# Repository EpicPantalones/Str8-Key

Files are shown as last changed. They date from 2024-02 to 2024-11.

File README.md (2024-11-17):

# The Str8-Key Keyboard

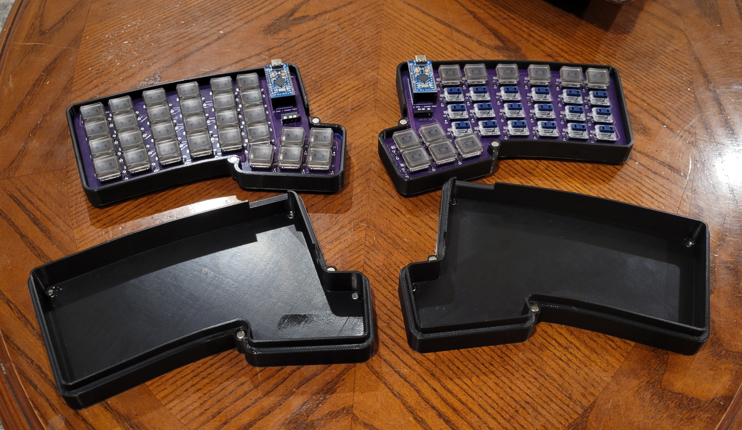
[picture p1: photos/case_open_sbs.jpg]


## Introduction

Welcome to Str8-Key, a custom mechanical keyboard in both form and function. Co-designed by Ethan Sorensen and John Rowberry, this ortho-linear, staggered, split keyboard is powered by dual Arduino Pro-Micro microcontrollers and connected via USB-C. Str8-Key bridges a fun engineering project with the great configurability of the QMK firmware, the result of which offers a unique and ergonomically safe typing experience! With 58 keys and infinite possibilities, this keyboard can be used to create layouts tailored perfectly to your workflow (or gameflow!). Built entirely from scratch, it remains an affordable project at just around $140, excluding 3D printing costs — actually a pretty good price for a fully customized typing experience.

Wow this is the 225 recitation! there are so many cool people here today.

## What You'll find in this Github:

You can look in the Tree.txt file to see a full list of all the files contained in the tree. Most of them are specific to our design, but you might find some jumping off points if you're interested in making your own.

## YAML Design

```YAML
metadata:
  engine: 4.0
  version: 1.2
  author: John Rowberry
  contact: johnrowberries@gmail.com
units:
  default_spread: 'cx'
  default_splay: 0
  default_width: 'cy'
  default_padding: 'cx'
  default_autobind: 10
  xspace: cx
  yspace: cy
  paddingy: yspace
...
and more
```

YAML (YAML Ain't Markup Language) is a human-readable data serialization format often used for configuration files. It focuses on simplicity and uses indentation to represent structure, making it easy to read and write. YAML supports key-value pairs, lists, and nested structures, and it's useful to us because Ergogen uses YAML structures to generate layouts for custom keyboards. Look at Flatfox's guide (linked below) for more info on the structure of the YAML code, but its really simple and in most cases you can reference an example like our code and get the right result.

## Board Layout

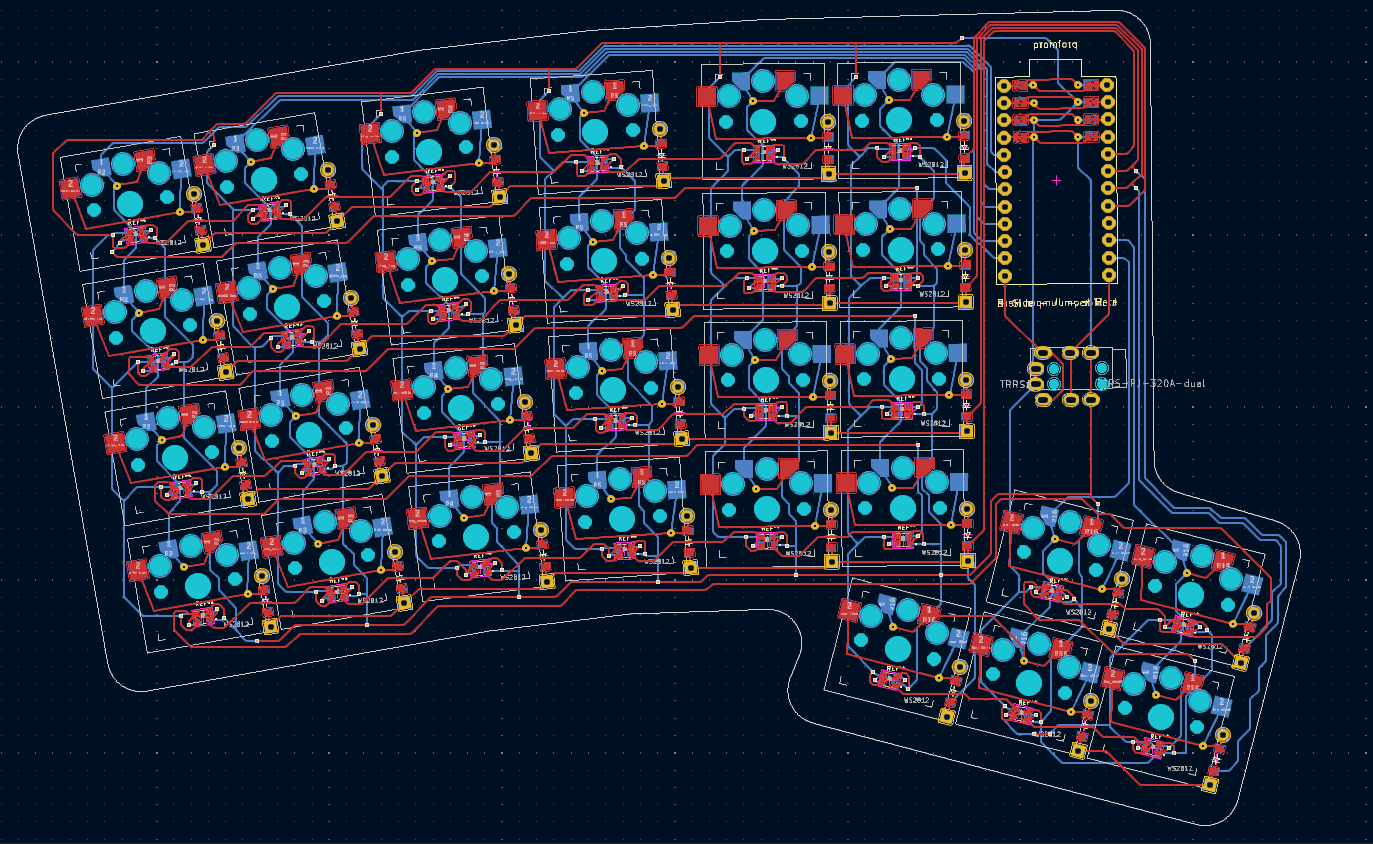
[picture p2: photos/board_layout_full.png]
the board layout

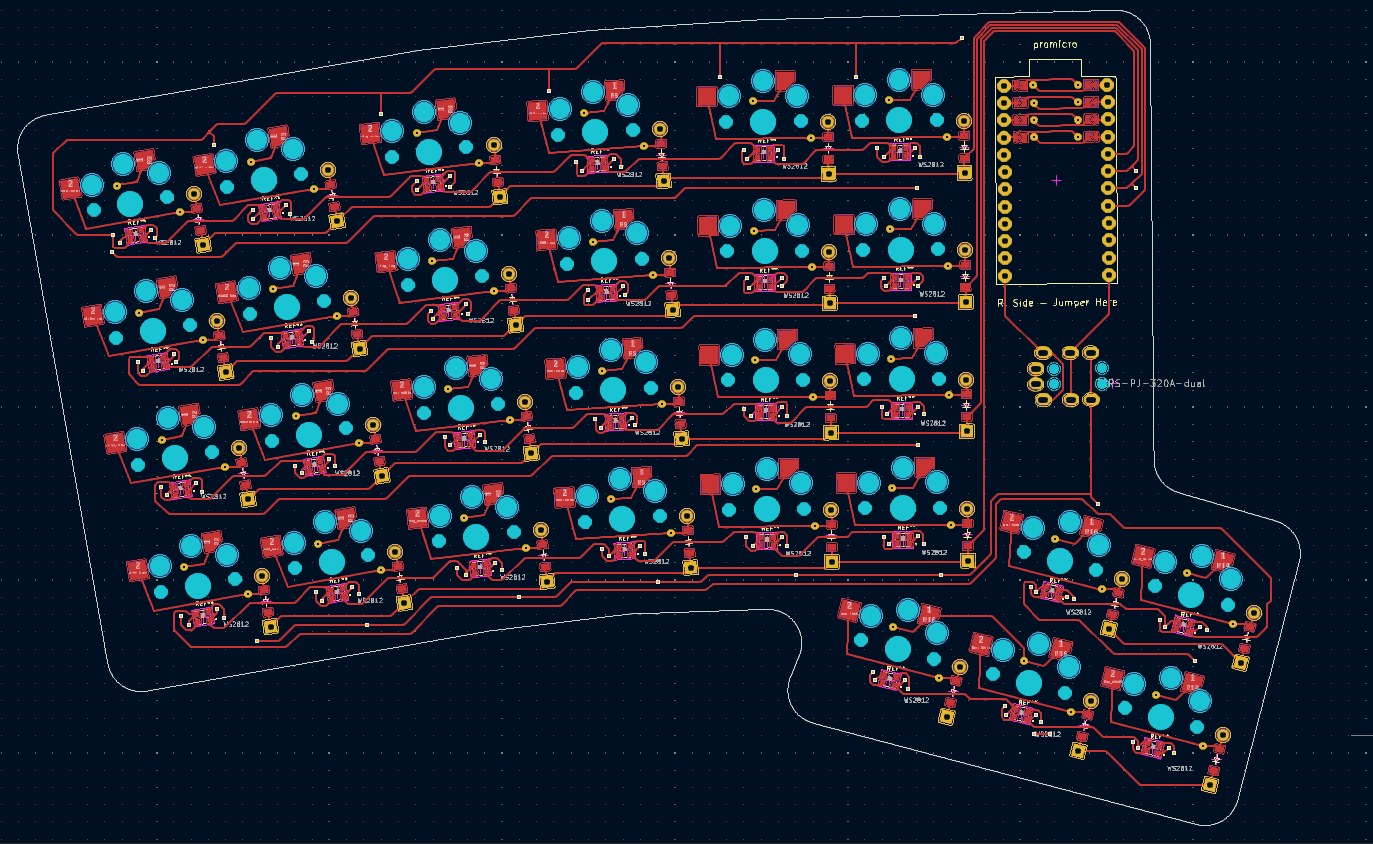
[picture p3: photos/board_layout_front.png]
the left board layout

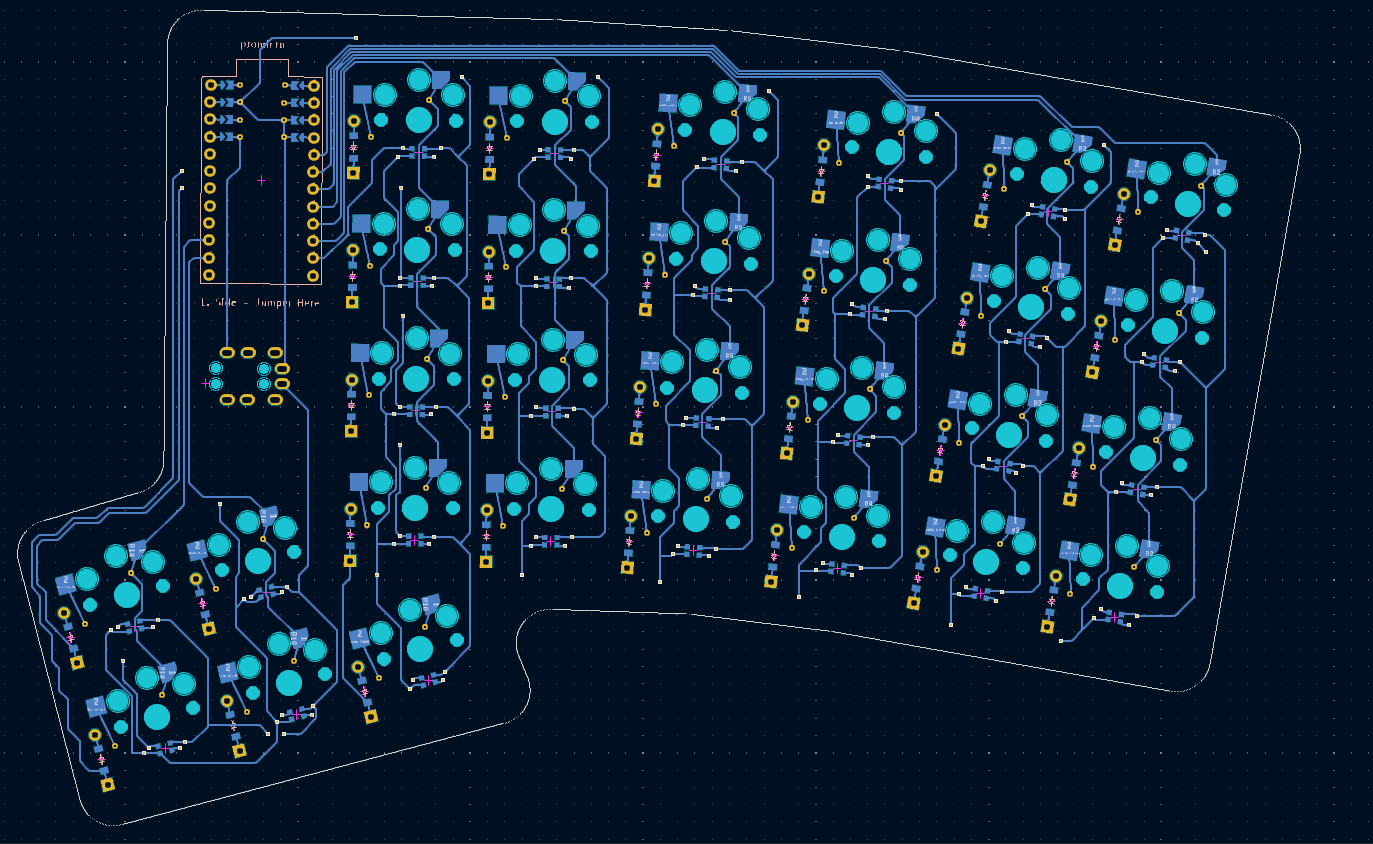
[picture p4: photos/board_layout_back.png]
the right board layout


## Final Product

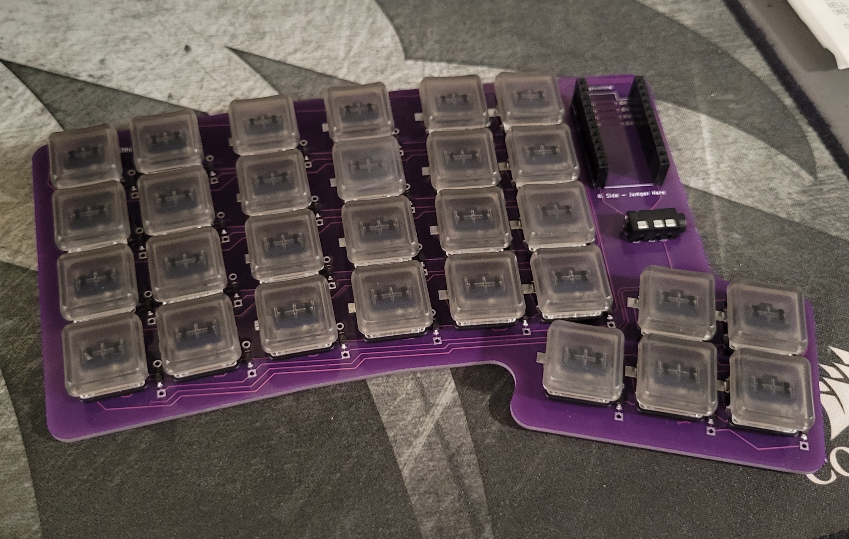
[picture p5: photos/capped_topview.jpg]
full keyboard top view

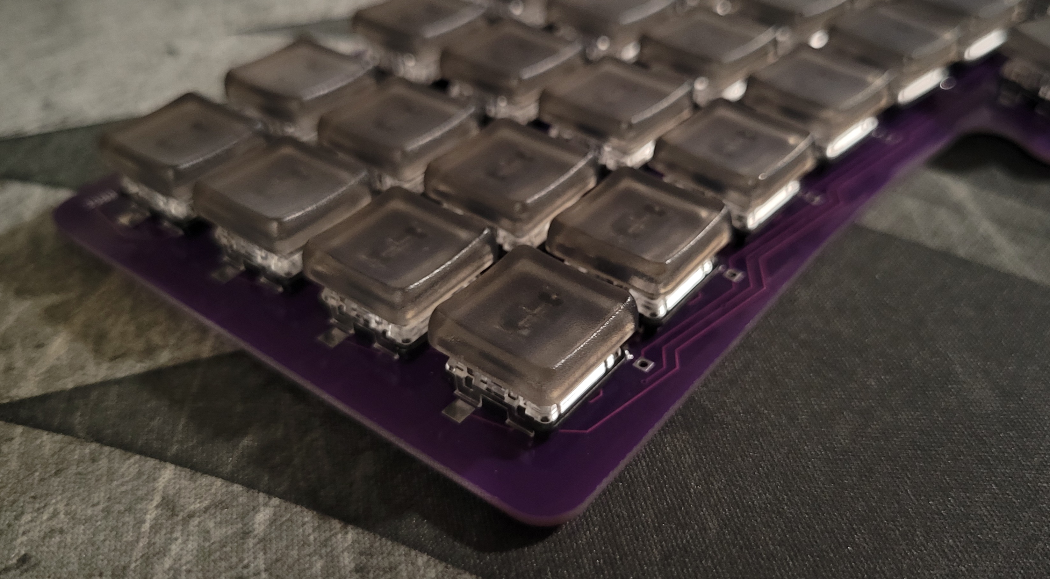
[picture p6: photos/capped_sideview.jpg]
keyboard side profile

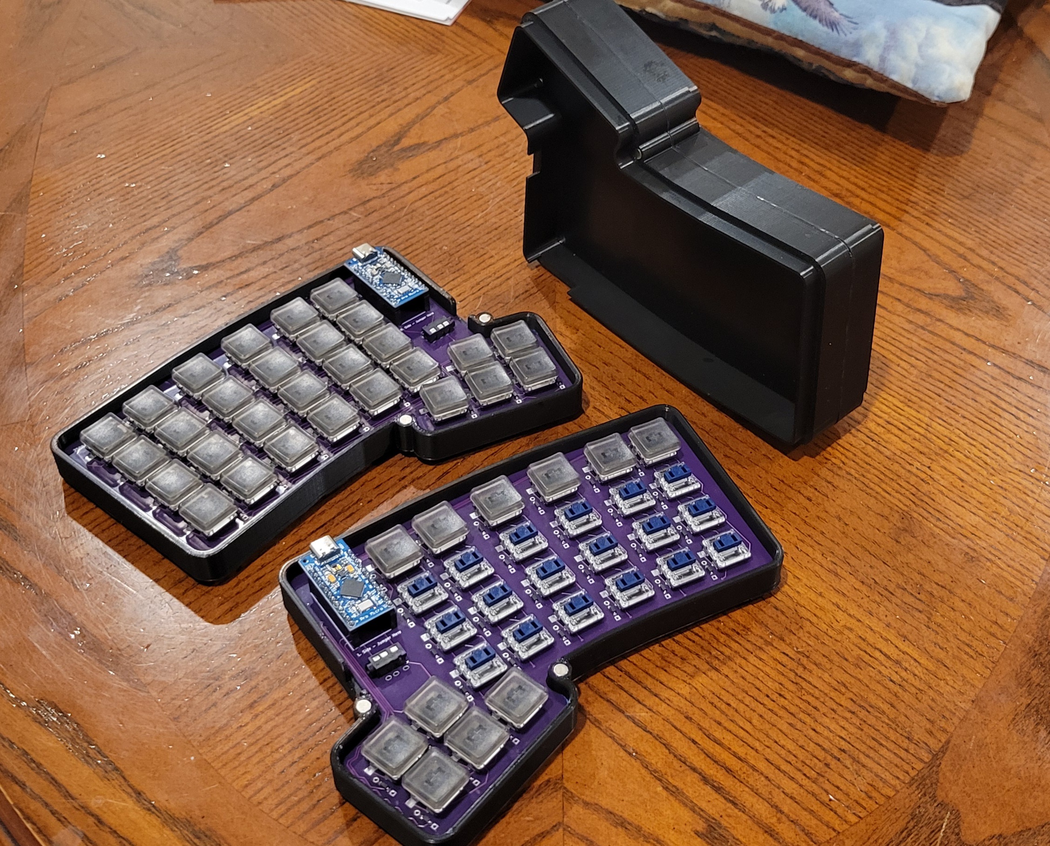
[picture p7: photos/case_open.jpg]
keyboard in opened case


## Resources we can provide for your own design:

The [**Ergogen guide by FlatFootFox**](https://flatfootfox.com/ergogen-introduction/) was instrumental in helping us bring Str8-Key to life, serving as both a comprehensive resource and our virtual teacher, alongside guidance from **BYU's IEEE Club**. Initially, we used the [**Ergogen Unofficial Website**](https://ergogen.cache.works/), which offers better real-time rendering in some cases compared to the [official site](https://ergogen.xyz/), but we eventually transitioned to running **Ergogen locally on Node**, as suggested in FlatFootFox's guide, for even greater control. [**QMK Firmware**](https://qmk.fm/) was chosen to program the keyboard, and though this is still a work in progress, it offers immense flexibility. Additionally, [**Carter's GitHub**](https://github.com/Virginia2244/BYU-IEEE-Keyboard-Project) project was invaluable, providing a template for the YAML files and saving us on more than one occasion during the build process.

## Resources for the footprint creation and KiCad stuff:

The documentation for the LEDs we chose came from the same **[Adafruit link where we purchased them](https://www.adafruit.com/product/4684)**, and I used this **[SNAP EDA footprint](https://www.snapeda.com/parts/WS2812-2020/Worldsemi/view-part/?company=BYU&)** as a starting point for the Ergogen code found in `footprints/epicpantalones/WS2812`. To ensure the choc switches fit and aligned properly, I referenced this **[choc switch datasheet](https://cdn-shop.adafruit.com/product-files/5113/CHOC+keyswitch_Kailh-CPG135001D01_C400229.pdf)**. The Ergogen code I wrote was primarily based on a guide to **[converting KiCad footprints to Ergogen](https://nilnil.notion.site/Convert-Kicad-Footprints-to-Ergogen-8340ce87ad554c69af4e3f92bc9a0898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)**, with some additional reference from this **[LED code](https://github.com/infused-kim/kb_ergogen_fp/blob/main/smd_0805.js)** that I used as a basis.

## The actual parts that we purchased:

We ordered the PCB from **[JLCPCB](https://jlcpcb.com/)**, and the price was incredibly affordable at just $13 plus shipping, totaling about $30 for five boards. The keys cost around $50, depending on the type, and we opted for **[frosted black choc switch keycaps](https://a.co/d/dT4MgD5)**, as the frosted look let the RGB lighting through. The LEDs were sourced from **[Adafruit](https://www.adafruit.com/product/4684)**. Our controller head unit is the **[Arduino Pro Micro](https://www.sparkfun.com/products/12640)**, a board we discovered during this project, and they are connected via an audio connector (links forthcoming). We also included hot-swap sockets for the choc switches, which makes customization easy, and control flow diodes, although we don't have the sourcing details or costs for those at the moment.

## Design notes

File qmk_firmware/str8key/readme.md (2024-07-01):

# str8key

str8key

*A short description of the keyboard/project*

* Keyboard Maintainer: [EpicPantalones](https://github.com/EpicPantalones)
* Hardware Supported: *The PCBs, controllers supported*
* Hardware Availability: *Links to where you can find this hardware*

Make example for this keyboard (after setting up your build environment):

    make str8key:default

Flashing example for this keyboard:

    make str8key:default:flash

See the [build environment setup](https://docs.qmk.fm/#/getting_started_build_tools) and the [make instructions](https://docs.qmk.fm/#/getting_started_make_guide) for more information. Brand new to QMK? Start with our [Complete Newbs Guide](https://docs.qmk.fm/#/newbs).

## Bootloader

Enter the bootloader in 3 ways:

* **Bootmagic reset**: Hold down the key at (0,0) in the matrix (usually the top left key or Escape) and plug in the keyboard
* **Physical reset button**: Briefly press the button on the back of the PCB - some may have pads you must short instead
* **Keycode in layout**: Press the key mapped to `QK_BOOT` if it is available

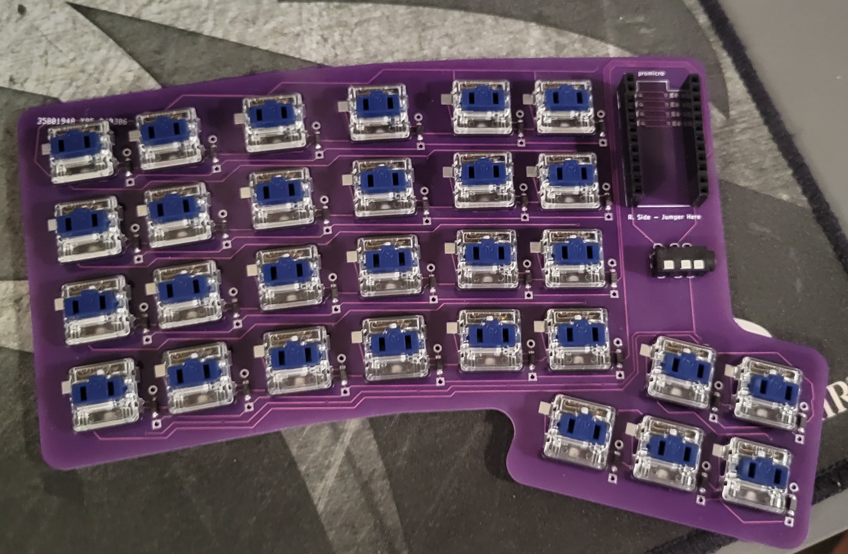
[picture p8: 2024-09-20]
photos/no_cap_topview.jpg

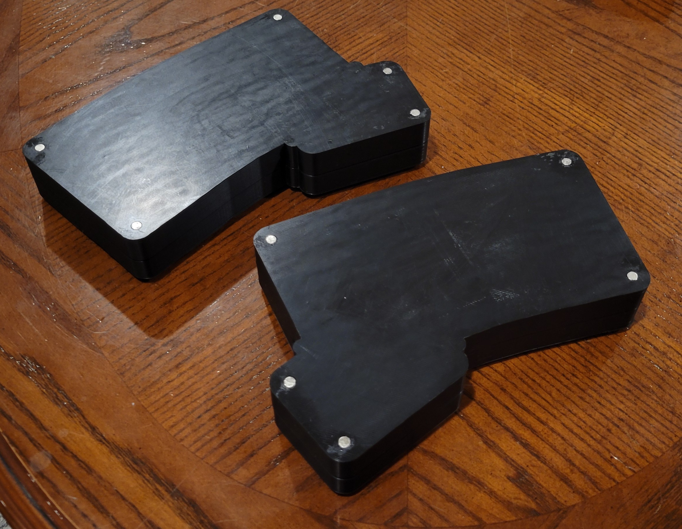
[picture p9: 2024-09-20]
photos/case_closed.jpg

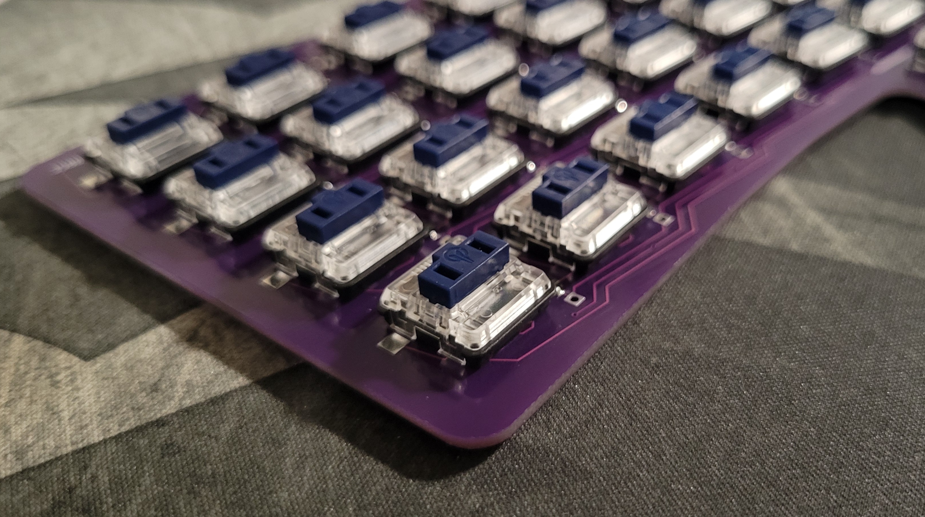
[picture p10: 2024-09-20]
photos/no_cap_sideview.jpg

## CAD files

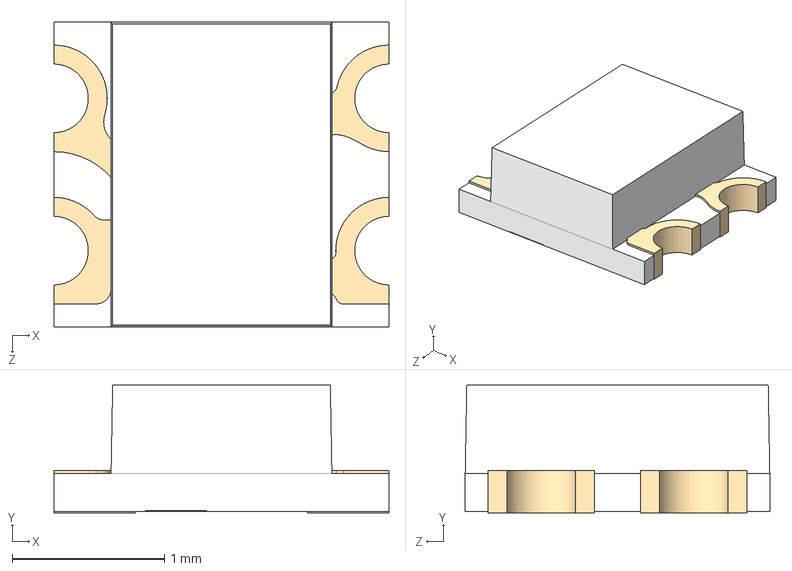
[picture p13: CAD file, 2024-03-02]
downloaded_footprints/WS2812-2020/WS2812-2020.step
2.20 x 0.84 x 2.00 mm

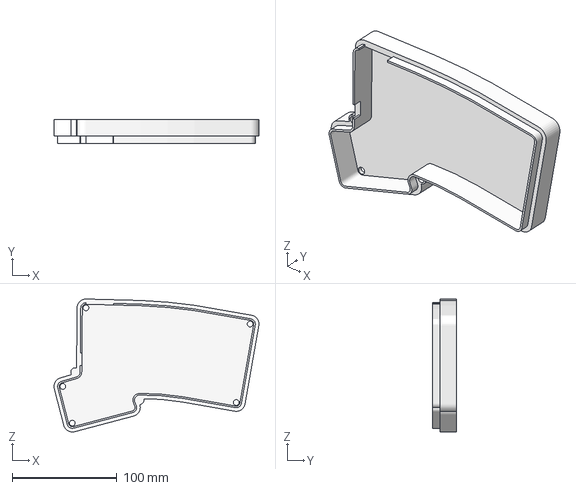
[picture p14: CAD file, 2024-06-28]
output/cases/Lid1.3mf
195.6 x 23.0 x 126.9 mm

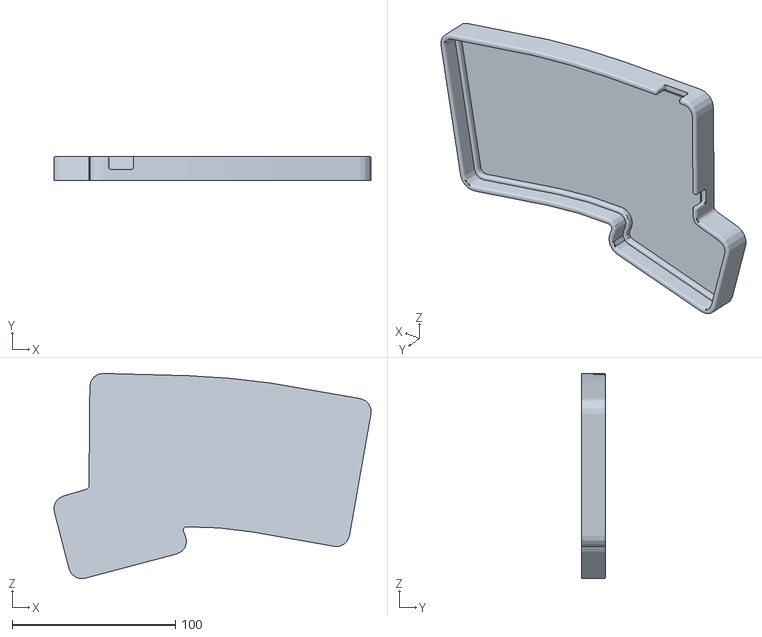
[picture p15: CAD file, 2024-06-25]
output/outlines/CaseAttempt1-L.stl
194.4 x 15.0 x 125.8

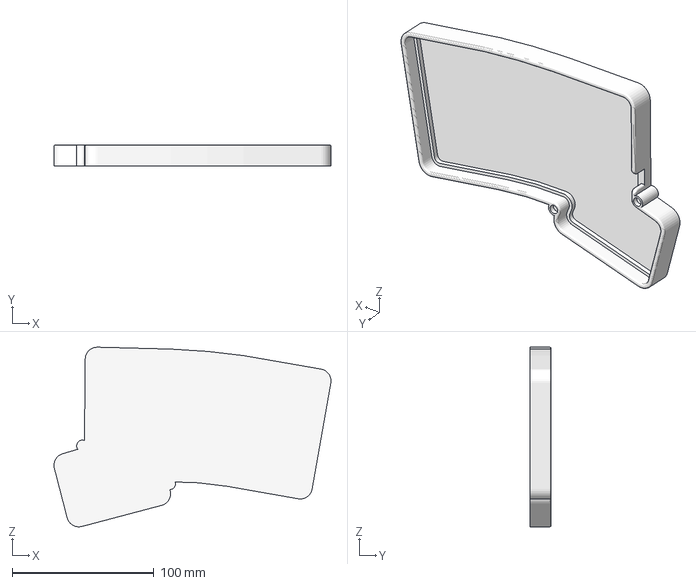
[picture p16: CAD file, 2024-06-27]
output/cases/CaseL.3mf
195.6 x 15.0 x 126.9 mm

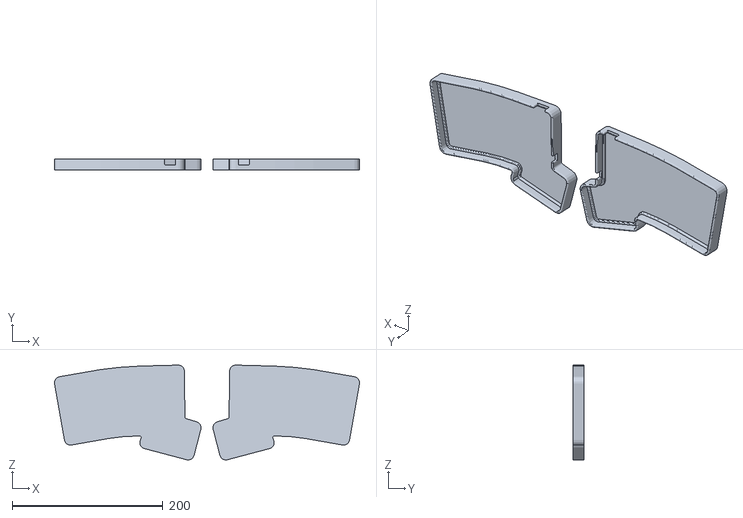
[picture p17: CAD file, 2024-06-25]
output/outlines/CaseAttempt1.stl
404.6 x 15.0 x 125.8

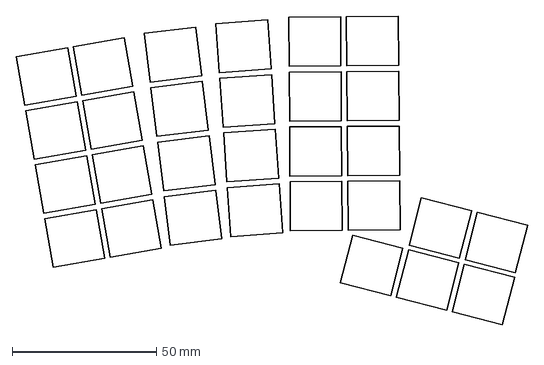
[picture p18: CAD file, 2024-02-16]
output/outlines/keyoutline.dxf
177.2 x 106.8 mm

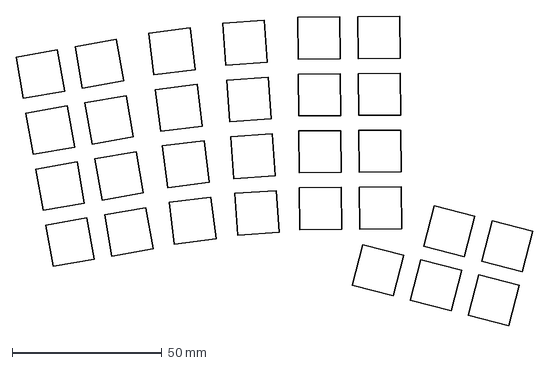
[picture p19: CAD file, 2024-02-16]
output/outlines/faceplate_keys.dxf
172.7 x 103.4 mm

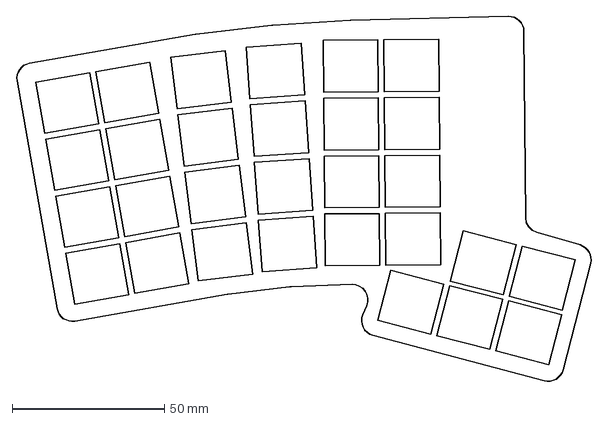
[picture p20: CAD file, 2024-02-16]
output/outlines/panel.dxf
189.3 x 120.1 mm

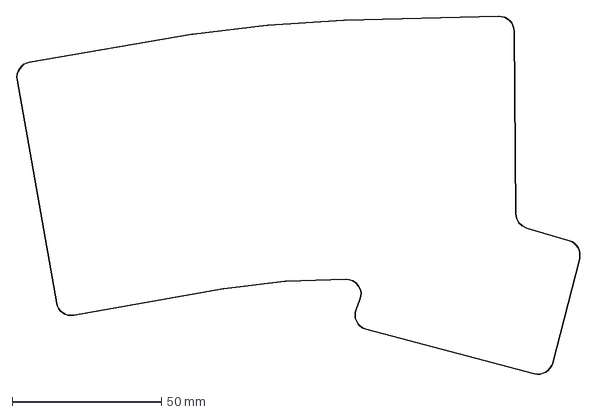
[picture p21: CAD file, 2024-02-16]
output/outlines/pcb_outline.dxf
189.3 x 120.1 mm

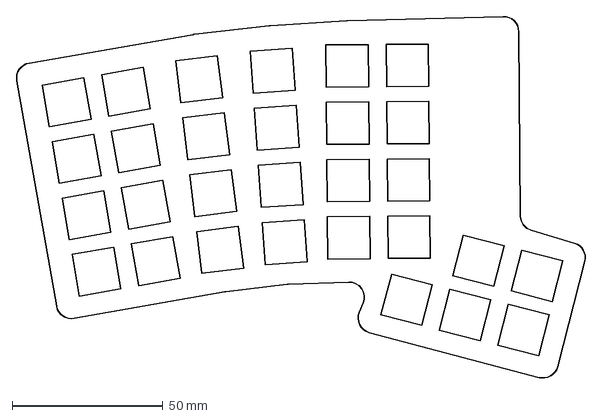
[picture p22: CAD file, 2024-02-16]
output/outlines/faceplate_panel.dxf
189.3 x 120.1 mm

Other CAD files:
output/outlines/CaseAttempt1-R.stl
output/cases/Case2.0_whole.ipt
output/cases/OldVersions/Case2.0_whole.0002.ipt
output/outlines/Case1.2.ipt
output/outlines/Lid1.0.ipt

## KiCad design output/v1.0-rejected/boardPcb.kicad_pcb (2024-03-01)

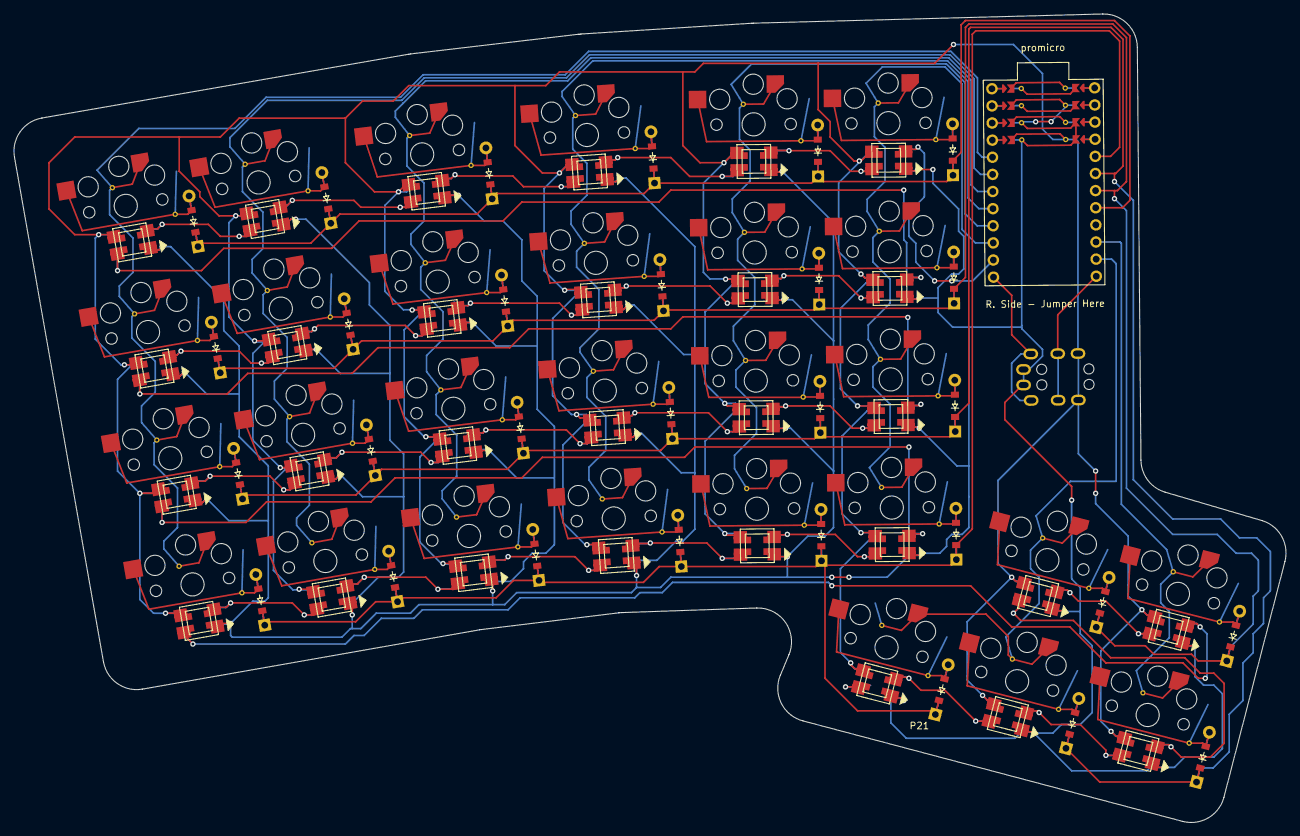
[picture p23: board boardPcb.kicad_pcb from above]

Board: 2 copper layers, 188.6 x 119.9 mm, 117 parts (0 on the bottom side), 73 nets.

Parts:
D1, D2, D3, D4, D5, D6, D7, D8, D9, D10, D11, D12, D13, D14, D15, D16, D17, D18, D19, D20, D21, D22, D23, D24, D25, D26, D27, D28, D29: ComboDiode
LED1, LED2, LED3, LED4, LED5, LED6, LED7, LED8, LED9, LED10, LED11, LED12, LED13, LED14, LED15, LED16, LED17, LED18, LED19, LED20, LED21, LED22, LED23, LED24, LED25, LED26, LED27, LED28, LED29, LED30, LED31, LED32, LED33, LED34, LED35, LED36, LED37, LED38, LED39, LED40, LED41, LED42, LED43, LED44, LED45, LED46, LED47, LED48, LED49, LED50, LED51, LED52, LED53, LED54, LED55, LED56, LED57, LED58: WS2812B
S1, S2, S3, S4, S5, S6, S7, S8, S9, S10, S11, S12, S13, S14, S15, S16, S17, S18, S19, S20, S21, S22, S23, S24, S25, S26, S27, S28, S29: PG1350
TRRS1: TRRS-PJ-320A-dual

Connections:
GND: LED1.3, LED1.33, LED2.3, LED2.33, LED3.3, LED3.33, LED4.3, LED4.33, LED5.3, LED5.33, LED6.3, LED6.33, LED7.3, LED7.33, LED8.3, LED8.33, LED9.3, LED9.33, LED10.3, LED10.33, LED11.3, LED11.33, LED12.3, LED12.33, LED13.3, LED13.33, LED14.3, LED14.33, LED15.3, LED15.33, LED16.3, LED16.33, LED17.3, LED17.33, LED18.3, LED18.33, LED19.3, LED19.33, LED20.3, LED20.33, LED21.3, LED21.33, LED22.3, LED22.33, LED23.3, LED23.33, LED24.3, LED24.33, LED25.3, LED25.33, LED26.3, LED26.33, LED27.3, LED27.33, LED28.3, LED28.33, LED29.3, LED29.33, LED30.3, LED30.33, LED31.3, LED31.33, LED32.3, LED32.33, LED33.3, LED33.33, LED34.3, LED34.33, LED35.3, LED35.33, LED36.3, LED36.33, LED37.3, LED37.33, LED38.3, LED38.33, LED39.3, LED39.33, LED40.3, LED40.33, LED41.3, LED41.33, LED42.3, LED42.33, LED43.3, LED43.33, LED44.3, LED44.33, LED45.3, LED45.33, LED46.3, LED46.33, LED47.3, LED47.33, LED48.3, LED48.33, LED49.3, LED49.33, LED50.3, LED50.33, LED51.3, LED51.33, LED52.3, LED52.33, LED53.3, LED53.33, LED54.3, LED54.33, LED55.3, LED55.33, LED56.3, LED56.33, LED57.3, LED57.33, LED58.3, LED58.33, TRRS1.1
L001: LED20.4, LED20.44, LED24.2, LED24.22, LED49.4, LED49.44, LED53.2, LED53.22
L002: LED16.4, LED16.44, LED20.2, LED20.22, LED45.4, LED45.44, LED49.2, LED49.22
L003: LED12.4, LED12.44, LED16.2, LED16.22, LED41.4, LED41.44, LED45.2, LED45.22
L004: LED8.4, LED8.44, LED12.2, LED12.22, LED37.4, LED37.44, LED41.2, LED41.22
L005: LED4.4, LED4.44, LED8.2, LED8.22, LED33.4, LED33.44, LED37.2, LED37.22
L006: LED4.2, LED4.22, LED23.4, LED23.44, LED33.2, LED33.22, LED52.4, LED52.44
L007: LED19.4, LED19.44, LED23.2, LED23.22, LED48.4, LED48.44, LED52.2, LED52.22
L008: LED15.4, LED15.44, LED19.2, LED19.22, LED44.4, LED44.44, LED48.2, LED48.22
L009: LED11.4, LED11.44, LED15.2, LED15.22, LED40.4, LED40.44, LED44.2, LED44.22
L010: LED7.4, LED7.44, LED11.2, LED11.22, LED36.4, LED36.44, LED40.2, LED40.22
L011: LED3.4, LED3.44, LED7.2, LED7.22, LED32.4, LED32.44, LED36.2, LED36.22
L012: LED3.2, LED3.22, LED22.4, LED22.44, LED32.2, LED32.22, LED51.4, LED51.44
L013: LED18.4, LED18.44, LED22.2, LED22.22, LED47.4, LED47.44, LED51.2, LED51.22
L014: LED14.4, LED14.44, LED18.2, LED18.22, LED43.4, LED43.44, LED47.2, LED47.22
L015: LED10.4, LED10.44, LED14.2, LED14.22, LED39.4, LED39.44, LED43.2, LED43.22
L016: LED6.4, LED6.44, LED10.2, LED10.22, LED35.4, LED35.44, LED39.2, LED39.22
L017: LED2.4, LED2.44, LED6.2, LED6.22, LED31.4, LED31.44, LED35.2, LED35.22
L018: LED2.2, LED2.22, LED21.4, LED21.44, LED31.2, LED31.22, LED50.4, LED50.44
L019: LED17.4, LED17.44, LED21.2, LED21.22, LED46.4, LED46.44, LED50.2, LED50.22
L020: LED13.4, LED13.44, LED17.2, LED17.22, LED42.4, LED42.44, LED46.2, LED46.22
L021: LED9.4, LED9.44, LED13.2, LED13.22, LED38.4, LED38.44, LED42.2, LED42.22
L022: LED5.4, LED5.44, LED9.2, LED9.22, LED34.4, LED34.44, LED38.2, LED38.22
L023: LED1.4, LED1.44, LED5.2, LED5.22, LED30.4, LED30.44, LED34.2, LED34.22
L024: LED1.2, LED1.22, LED29.4, LED29.44, LED30.2, LED30.22, LED58.4, LED58.44
L025: LED28.4, LED28.44, LED29.2, LED29.22, LED57.4, LED57.44, LED58.2, LED58.22
L026: LED27.4, LED27.44, LED28.2, LED28.22, LED56.4, LED56.44, LED57.2, LED57.22
L027: LED26.4, LED26.44, LED27.2, LED27.22, LED55.4, LED55.44, LED56.2, LED56.22
L028: LED25.4, LED25.44, LED26.2, LED26.22, LED54.4, LED54.44, LED55.2, LED55.22
L029: LED25.2, LED25.22, LED54.2, LED54.22
P2: S1.1, S1.2, S2.1, S2.2, S3.1, S3.2, S4.1, S4.2
P3: S5.1, S5.2, S6.1, S6.2, S7.1, S7.2, S8.1, S8.2
P4: S9.1, S9.2, S10.1, S10.2, S11.1, S11.2, S12.1, S12.2
P5: S13.1, S13.2, S14.1, S14.2, S15.1, S15.2, S16.1, S16.2
P6: S17.1, S17.2, S18.1, S18.2, S19.1, S19.2, S20.1, S20.2
P7: S21.1, S21.2, S22.1, S22.2, S23.1, S23.2, S24.1, S24.2
P8: LED24.4, LED24.44, LED53.4, LED53.44
P14: S27.1, S27.2, S29.1, S29.2
P16: S25.1, S25.2, S26.1, S26.2, S28.1, S28.2
P18: D4.1, D8.1, D12.1, D16.1, D20.1, D24.1
P19: D3.1, D7.1, D11.1, D15.1, D19.1, D23.1, D28.1, D29.1
P20: D2.1, D6.1, D10.1, D14.1, D18.1, D22.1, D26.1, D27.1
P21: D1.1, D5.1, D9.1, D13.1, D17.1, D21.1, D25.1
VCC: LED1.1, LED1.11, LED2.1, LED2.11, LED3.1, LED3.11, LED4.1, LED4.11, LED5.1, LED5.11, LED6.1, LED6.11, LED7.1, LED7.11, LED8.1, LED8.11, LED9.1, LED9.11, LED10.1, LED10.11, LED11.1, LED11.11, LED12.1, LED12.11, LED13.1, LED13.11, LED14.1, LED14.11, LED15.1, LED15.11, LED16.1, LED16.11, LED17.1, LED17.11, LED18.1, LED18.11, LED19.1, LED19.11, LED20.1, LED20.11, LED21.1, LED21.11, LED22.1, LED22.11, LED23.1, LED23.11, LED24.1, LED24.11, LED25.1, LED25.11, LED26.1, LED26.11, LED27.1, LED27.11, LED28.1, LED28.11, LED29.1, LED29.11, LED30.1, LED30.11, LED31.1, LED31.11, LED32.1, LED32.11, LED33.1, LED33.11, LED34.1, LED34.11, LED35.1, LED35.11, LED36.1, LED36.11, LED37.1, LED37.11, LED38.1, LED38.11, LED39.1, LED39.11, LED40.1, LED40.11, LED41.1, LED41.11, LED42.1, LED42.11, LED43.1, LED43.11, LED44.1, LED44.11, LED45.1, LED45.11, LED46.1, LED46.11, LED47.1, LED47.11, LED48.1, LED48.11, LED49.1, LED49.11, LED50.1, LED50.11, LED51.1, LED51.11, LED52.1, LED52.11, LED53.1, LED53.11, LED54.1, LED54.11, LED55.1, LED55.11, LED56.1, LED56.11, LED57.1, LED57.11, LED58.1, LED58.11, TRRS1.4
far2_thumb2: D29.2, S29.2
far_thumb: D27.2, S27.2
home2_thumb2: D28.2, S28.2
home_thumb: D26.2, S26.2
middle_bottom: D13.2, S13.2
middle_middle: D14.2, S14.2
middle_number: D16.2, S16.2
middle_top: D15.2, S15.2
near_thumb: D25.2, S25.2
pink2_bottom: D5.2, S5.2
pink2_middle: D6.2, S6.2
pink2_number: D8.2, S8.2
pink2_top: D7.2, S7.2
pinky1_bottom: D1.2, S1.2
pinky1_middle: D2.2, S2.2
pinky1_number: D4.2, S4.2
pinky1_top: D3.2, S3.2
pointer2_bottom: D21.2, S21.2
pointer2_middle: D22.2, S22.2
pointer2_number: D24.2, S24.2
pointer2_top: D23.2, S23.2
pointer_bottom: D17.2, S17.2
pointer_middle: D18.2, S18.2
pointer_number: D20.2, S20.2
pointer_top: D19.2, S19.2
ring_bottom: D9.2, S9.2
ring_middle: D10.2, S10.2
ring_number: D12.2, S12.2
ring_top: D11.2, S11.2

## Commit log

2024-02-08 Updated PCB outline
    Now contains enough room to fit keyboard controller (0.7in x 1.3in or ~18mm x 33mm) with ~5mm excess
2024-02-08 final outline update - send to print
2024-02-08 PCB updates :D
2024-02-16 Running local Ergogen now
    [boardPcb.kicad_pcb, faceplate_keys.dxf, faceplate_panel.dxf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]
2024-02-16 created some PCB stuff; prep for layout
    [boardPcb.kicad_pcb]
2024-02-27 ready to do official layout
    [boardPcb.kicad_pcb]
2024-02-27 finished initial layout; pending 3 reviews
    [boardPcb.kicad_pcb]
2024-02-27 tweak two remove 2 redundant vias
    [boardPcb.kicad_pcb]
2024-03-01 Layout reviewed; revision 2
    [boardPcb-B_Cu.gbr, boardPcb-B_Mask.gbr, boardPcb-B_Paste.gbr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]
2024-03-02 downloaded some help docs
    [WS2812-2020.step]
2024-03-02 cleaned stuff
    [boardPcb-B_Cu.gbr, boardPcb-B_Mask.gbr, boardPcb-B_Paste.gbr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]
2024-03-02 created custom LED footprint
    [boardPcb.kicad_pcb]
2024-03-02 renamed folder for clarity
    [boardPcb-B_Cu.gbr, boardPcb-B_Mask.gbr, boardPcb-B_Paste.gbr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]
2024-03-02 testing new footprint - almost redy to relayout
2024-03-04 finished rev. 2.0 with 2x2 LEDs; review time
    [boardPcb-B_Cu.gbr, boardPcb-B_Mask.gbr, boardPcb-B_Paste.gbr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]
2024-03-04 created final output version; sent for creation!
    [boardPcb-B_Cu.gbr, boardPcb-B_Mask.gbr, boardPcb-B_Paste.gbr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]
2024-03-29 Create WithCaseInfo
    Same project but minus the pcb and plus the case info
2024-06-25 Added some test cases files - we shall see
    [CaseAttempt1-L.stl, CaseAttempt1-R.stl, CaseAttempt1.stl]
2024-06-26 Modified case for magnets and made it slightly big
    [Case1.2.ipt]
2024-06-26 Unfinished Lid added
    [Lid1.0.ipt]
2024-06-27 added final (hopefully) model of case
    [CaseL.3mf]
2024-06-28 first attempt at lid
    [Lid1.3mf]
2024-09-20 making new case
    [Case2.0_whole.0002.ipt, Case2.0_whole.ipt]
